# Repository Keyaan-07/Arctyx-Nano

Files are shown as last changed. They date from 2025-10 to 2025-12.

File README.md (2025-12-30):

# Arctyx Nano

Arctyx Nano is an FPGA development board carrying the ICE40UP5K FPGA from Lattice. It also carries RP2350A from Raspberry Pi.  

Check out the board on [KiCanvas](https://kicanvas.org/?github=https://github.com/Keyaan-07/Arctyx-Nano/tree/main/hardware_Arctyx-Nano)

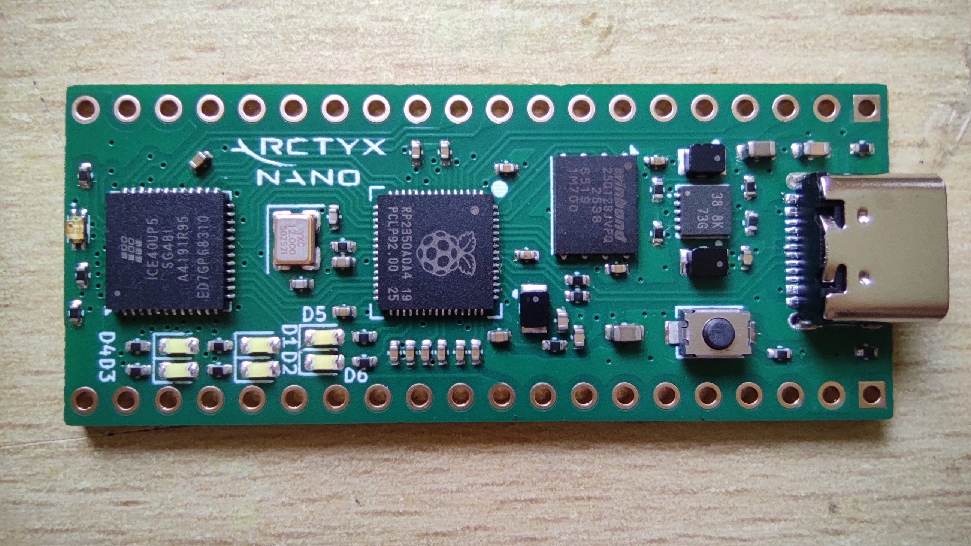
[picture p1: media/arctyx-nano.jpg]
assembled PCB

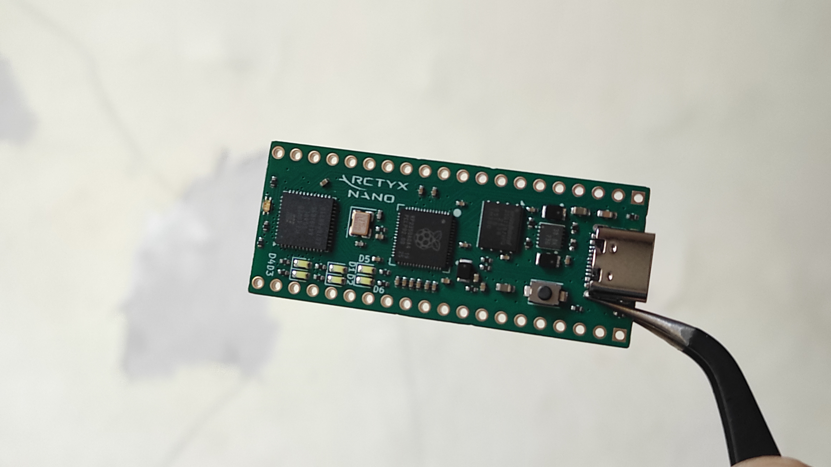
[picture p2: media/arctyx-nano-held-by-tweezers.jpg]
arctyx nano held by tweezers

  

## Features:
> Dual core ARM Cortex-M33 Processor (also everything else the RP2350 has)  
> 8 channel bus connecting the FPGA and the RP2350A  
> 128Mbit of Flash.  
> 6 General Purpose LEDs (4x for FPGA and 2x for RP2350A).  
> RGB LED connected to the FPGA.  
> Onboard Dual Stepdown Convertor.    
> USB Boot Button for RP2350A.  

## IO Pin mapping:

| Programmer Pin | Pin on FPGA | Pin on RP2350A |
| --- | --- | --- |
| CSn | IOB_35b_SPI_SS  | GPIO17 |
| MOSI | IOB_33b_SPI_SI  | GPIO19 |
| MISO | IOB_32a_SPI_SO  | GPIO20 |
| SCLK | IOB_34a_SPI_SCK | GPIO18 |

| Pin Label | Pin on FPGA | Pin label | Pin on FPGA |
| --- | --- | --- | --- |
| IO1 | IOT_41a | IO11 | IOB_4a |
| IO2 | IOT_42b | IO12 | IOB_6a |
| IO3 | IOT_43a | IO13 | IOB_9b |
| IO4 | IOT_44b | IO14 | IOB_9a |
| IO5 | IOT_46b | IO15 | IOB_13b |
| IO6 | IOT_48b | IO16 | IOB_16a |
| IO7 | IOT_45a | IO17 | IOB_18a |
| IO8 | IOT_50b | IO18 | IOB_20a |
| IO9 | IOT_51a | IO19 | IOB_22a |
| IO10 | IOT_49a | IO20 | IOB_24a |

| BUS Pin | Pin on FPGA | Pin on RP2350A |
| --- | --- | --- |
| BUS0 | IOT_38b | GPIO9 |
| BUS1 | IOT_39a | GPIO10 |
| BUS2 | IOT_36b | GPIO11 |
| BUS3 | IOT_37a | GPIO12 |
| BUS4 | IOB_23b | GPIO13 |
| BUS5 | IOB_25b_G3  | GPIO14 |
| BUS6 | IOB_29b | GPIO15 |
| BUS7 | IOB_31b | GPIO16 |

| LED | Pin On FPGA/MCU  |
| --- | ---  |
| D1  | IOB_0a |
| D2  | IOB_2a |
| D3  | IOB_5b |
| D4  | IOB_3b_G6 |
| D5  | GPIO21 |
| D6  | GPIO22 |
| RGB | RGB0, RGB1, RGB2 |

## BOM
| Item | Cost  | Note |
| --- | ----- | --- |
| PCB | 17.8  | 4-Layers |
| PCBA | 52.77 | Kinda Dense board  |
| Shipping charges  | 9.28  | |
| coupon Discount | \-9 | |
| Total | 70.85 | USD |

### PCB Components Breakdown
| Designator | Designation | Footprint | Quantity | Amount | JLCPCB Lib type | JLCPCB Part Number |
| --- | --- | --- | --- | --- | --- | --- |
| C1,C2 | 15p | 0402 | 4 | 0.004  | Basic | C1548 |
| C10,C11,C12,C13,C14,C15,C17,C18,C19,C21,C6,C7,C8,C9 | 100n | 0402 | 28 | 0.0336 | Basic | C1525 |
| C16,C23,C3,C4,C5 | 4.7u | 0402 | 10 | 0.049  | Basic | C23733 |
| C20,C22 | 22u | 0603 | 4 | 0.0348 | Basic | C59461 |
| C24 | 10u | 0603 | 2 | 0.0112 | Basic | C19702 |
| D1,D2,D3,D4,D5,D6 | LED | 0603 | 12 | 0.1224 | Extended | C2290 |
| L1,L2,L3 | AOTA-B201610S3R3-101-T | IND-SMD_L2.0-W1.6_AOTA-B201610S3R3-101-T | 6 | 1.0782 | Extended | C42411119 |
| R1,R2 | 5.1k | 0402 | 4 | 0.002  | Basic | C25905 |
| R3,R4 | 27 | 0402 | 20 | 0.012  | Extended | C138021 |
| R5,R7 | 1k | 0402 | 4 | 0.0024 | Basic | C11702 |
| R6 | 33 | 0402 | 2 | 0.0012 | Basic | C25105 |
| R10,R9 | 51k | 0402 | 4 | 0.0024 | Basic | C25794 |
| R11 | 100k | 0402 | 2 | 0.0012 | Basic | C25741 |
| R12 | 22k | 0402 | 2 | 0.0012 | Basic | C25768 |
| R13 | 120 | 0402 | 2 | 0.0012 | Basic | C25079 |
| R14,R15,R16,R17,R18,R19,R20,R21 | 100 | 0402 | 16 | 0.008  | Basic | C25076 |
| SW1 | SW_Push | SW-SMD_L3.9-W3.0-P4.45 | 2 | 0.0846 | Basic | C720477 |
| U1 | ICE40UP5K-SG48ITR | QFN-48-1EP_7x7mm_P0.5mm_EP5.6x5.6mm | 2 | 11.352 | Extended | C2678152 |
| U2 | RP2350A-QFN60 | RP2350A_QFN-60_EP_7.75x7.75_Pitch0.4mm | 2 | 3.195  | Extended | C42411118 |
| U3 | W25Q128JVP | WSON-8-1EP_6x5mm_P1.27mm_EP3.4x4.3mm | 2 | 2.472  | Extended | C2441427 |
| U4 | RT8075ZQW | WDFN-10_L3.0-W3.0-P0.50-BL-EP | 2 | 0.864  | Extended | C250416 |
| U5 | TJ-S1608SW6TDSLCCYRGB-A5 | LED-ARRAY-SMD_4P-L1.6-W0.8-BL-FD | 6 | 0.4314 | Extended | C5356078 |
| Y1 | Crystal_GND24 | Crystal_SMD_3225-4Pin_3.2x2.5mm | 2 | 0.1290  | Basic | C9002 |
| J1 | USB_C_Receptacle_USB2.0_16P | USB_C_Receptacle_XKB_U262-16XN-4BVC11 | 0 | 0 | Do Not Place | Do Not Place |

## License and Contribution

[MIT License](/LICENSE)

Open to contributions in both software and hardware!

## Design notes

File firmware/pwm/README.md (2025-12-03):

# PWM

This code makes all 3 RGB LEDs present on the Arctyx Nano have the fading effect. Here's a demo video:

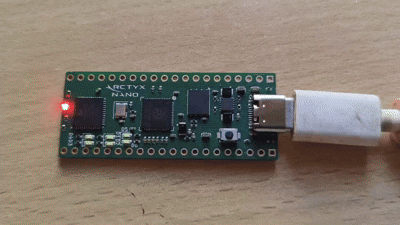
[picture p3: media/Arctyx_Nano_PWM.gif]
PWM Demo GIF


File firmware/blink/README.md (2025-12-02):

# Blink!

This code makes the RGB LEDs on the FPGA toggle. Here's a demo video:

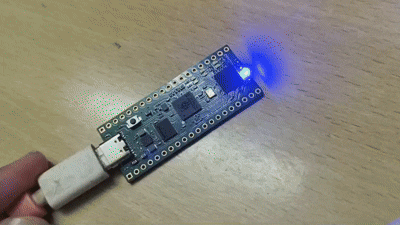
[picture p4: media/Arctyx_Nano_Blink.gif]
Arctyx Nano Blink


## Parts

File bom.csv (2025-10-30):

Item | Cost | Note
PCB | 17.8 | 4-Layers
PCBA | 52.77 | Kinda Dense board
Shipping from JLC | 9.28
coupon Discount | -9 | SMT monthly coupon
Total | 70.85 | USD

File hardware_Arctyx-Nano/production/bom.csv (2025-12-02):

Designator | Footprint | Quantity | Value | LCSC Part #
C1, C2 | 0402 | 2 | 15p
C10, C11, C12, C13, C14, C15, C17, C18, C19, C21, C6, C7, C8, C9 | 0402 | 14 | 100n
C16, C23, C3, C4, C5 | 0402 | 5 | 4.7u
C20, C22 | 0603 | 2 | 22u
C24 | 0603 | 1 | 10u
D1, D2, D3, D4, D5, D6 | 0603 | 6 | LED
J1 | USB_C_Receptacle_XKB_U262-16XN-4BVC11 | 1 | USB_C_Receptacle_USB2.0_16P
J2, J3 | PinHeader_1x20_P2.54mm_Vertical | 2 | Conn_01x20_Pin
L1, L2, L3 | IND-SMD_L2.0-W1.6_AOTA-B201610S3R3-101-T | 3 | AOTA-B201610S3R3-101-T | C42411119
R1, R2 | 0402 | 2 | 5.1k
R10, R9 | 0402 | 2 | 51k
R11 | 0402 | 1 | 22k
R12 | 0402 | 1 | 100k
R13 | 0402 | 1 | 120
R14, R15, R16, R17, R18, R19, R20, R21 | 0402 | 8 | 100
R3, R4 | 0402 | 2 | 27
R5, R7 | 0402 | 2 | 1k
R6 | 0402 | 1 | 33
SW1 | SW-SMD_L3.9-W3.0-P4.45 | 1 | SW_Push
TP1, TP2, TP3, TP4, TP5, TP6, TP7 | TestPoint_Pad_D1.0mm | 7 | TestPoint_Alt
U1 | QFN-48-1EP_7x7mm_P0.5mm_EP5.6x5.6mm | 1 | ICE40UP5K-SG48ITR
U2 | RP2350A_QFN-60_EP_7.75x7.75_Pitch0.4mm | 1 | RP2350A-QFN60
U3 | WSON-8-1EP_6x5mm_P1.27mm_EP3.4x4.3mm | 1 | W25Q128JVP
U4 | WDFN-10_L3.0-W3.0-P0.50-BL-EP | 1 | RT8075ZQW | C250416
U5 | LED-ARRAY-SMD_4P-L1.6-W0.8-BL-FD | 1 | TJ-S1608SW6TDSLCCYRGB-A5 | C5356078
Y1 | Crystal_SMD_3225-4Pin_3.2x2.5mm | 1 | Crystal_GND24

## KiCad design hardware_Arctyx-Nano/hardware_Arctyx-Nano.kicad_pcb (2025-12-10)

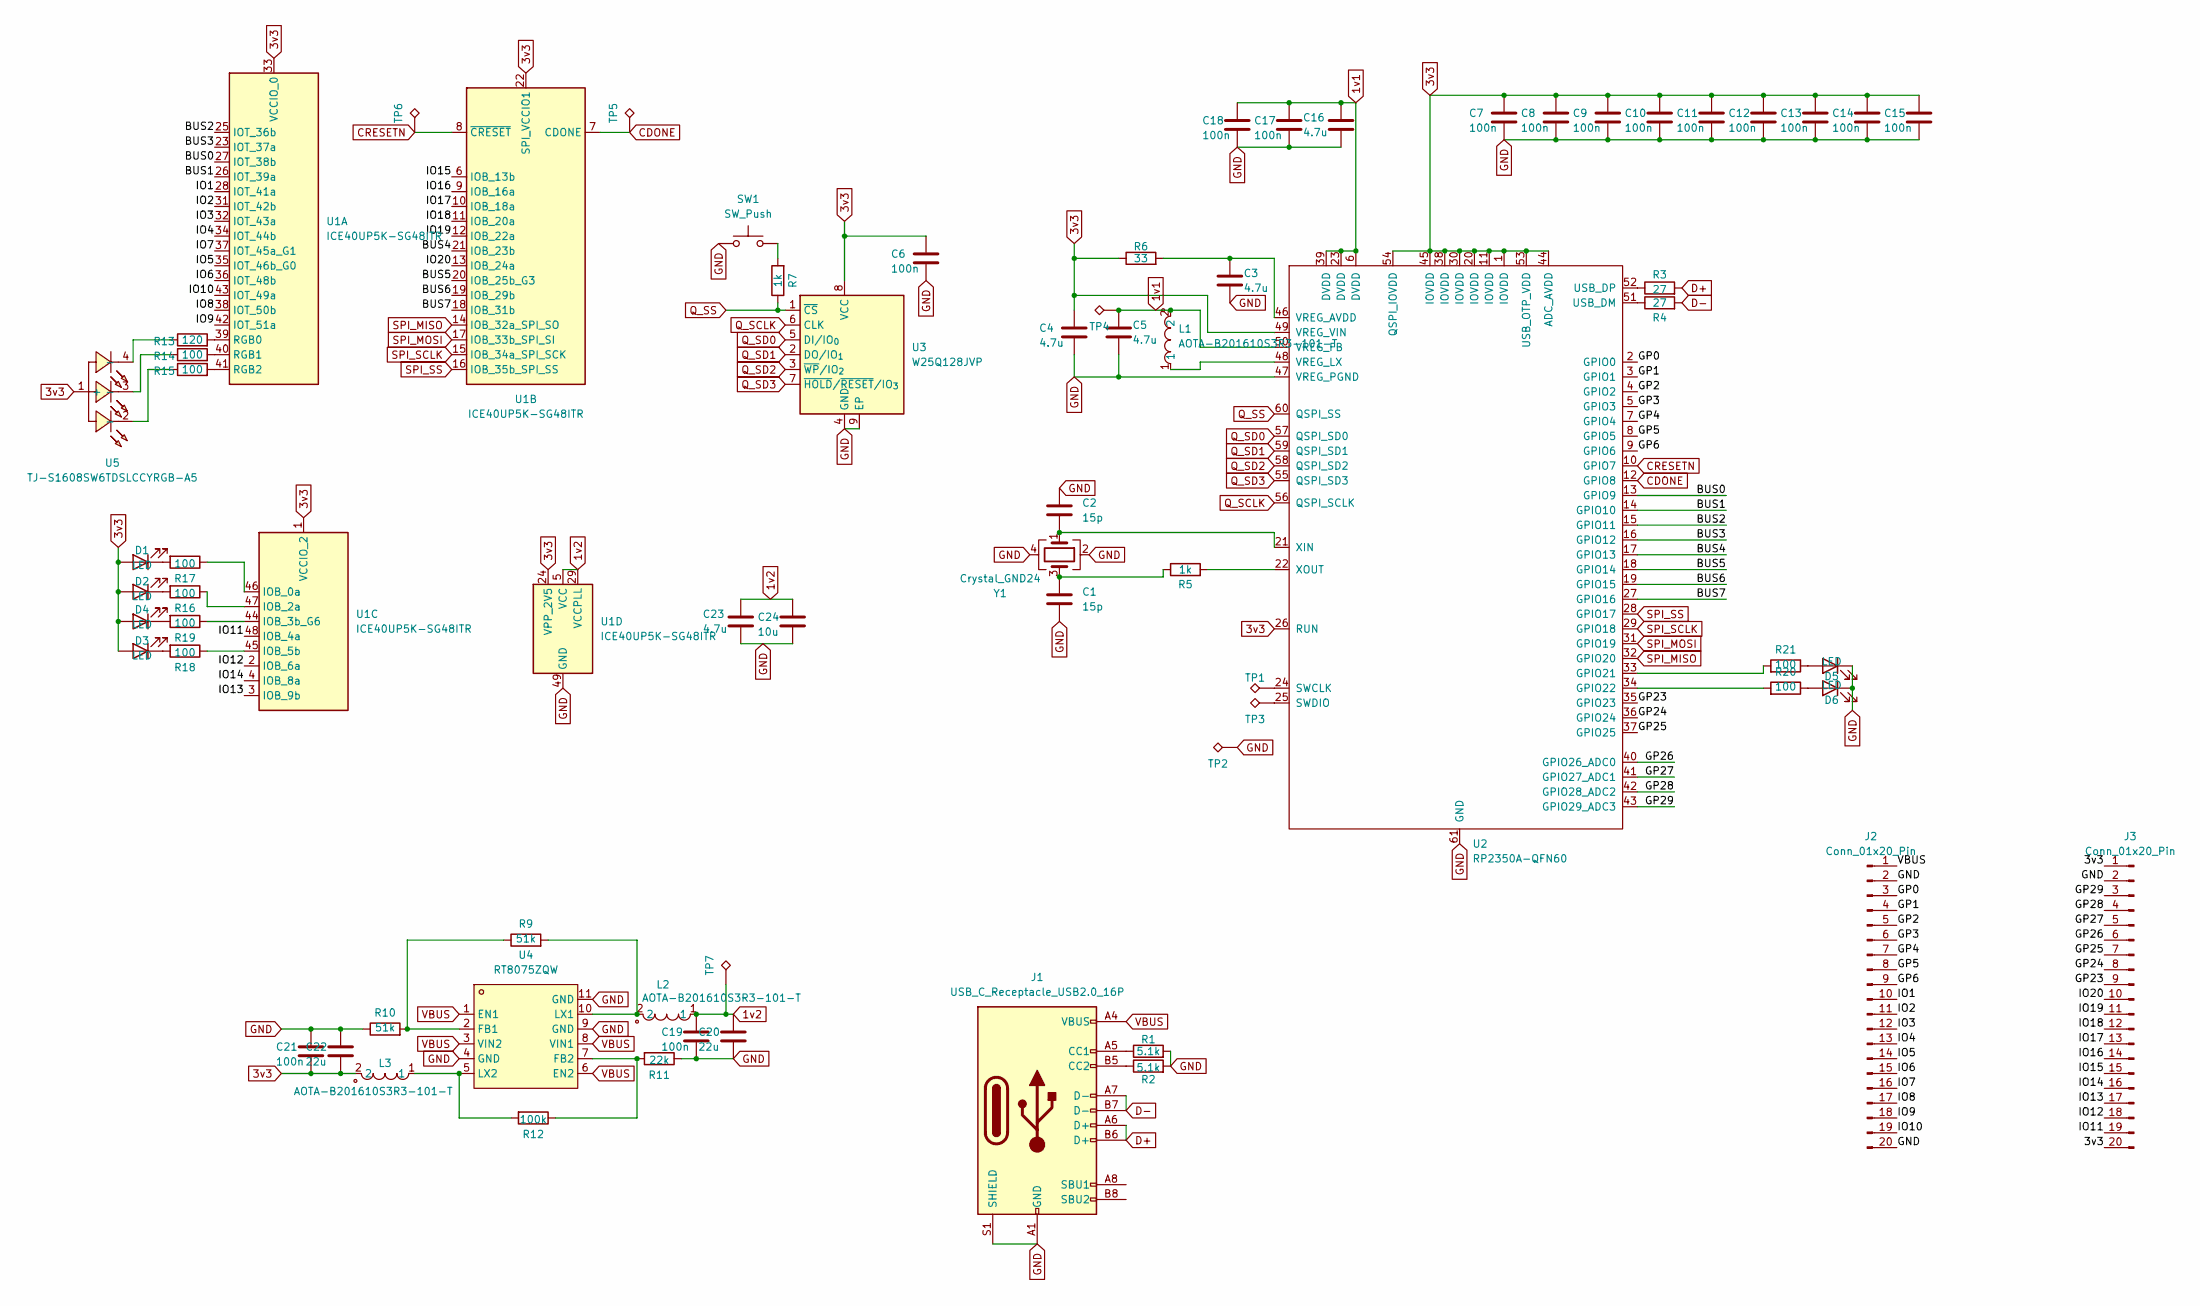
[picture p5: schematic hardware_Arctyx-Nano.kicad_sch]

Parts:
C1, C2: 15p; C_0402_1005Metric
C3, C4, C5, C16, C23: 4.7u; C_0402_1005Metric
C6, C7, C8, C9, C10, C11, C12, C13, C14, C15, C17, C18, C19, C21: 100n; C_0402_1005Metric
C20, C22: 22u; C_0603_1608Metric
C24: 10u; C_0603_1608Metric
D1, D2, D3, D4, D5, D6: LED; LED_0603_1608Metric
J1: USB_C_Receptacle_USB2.0_16P; USB_C_Receptacle_XKB_U262-16XN-4BVC11
J2, J3: Conn_01x20_Pin; PinHeader_1x20_P2.54mm_Vertical
L1, L2, L3: AOTA-B201610S3R3-101-T; IND-SMD_L2.0-W1.6_AOTA-B201610S3R3-101-T; LCSC Part C42411119
R1, R2: 5.1k; R_0402_1005Metric
R3, R4: 27; R_0402_1005Metric
R5, R7: 1k; R_0402_1005Metric
R6: 33; R_0402_1005Metric
R9, R10: 51k; R_0402_1005Metric
R11: 22k; R_0402_1005Metric
R12: 100k; R_0402_1005Metric
R13: 120; R_0402_1005Metric
R14, R15, R16, R17, R18, R19, R20, R21: 100; R_0402_1005Metric
SW1: SW_Push; SW-SMD_L3.9-W3.0-P4.45
TP1, TP2, TP3, TP4, TP5, TP6, TP7: TestPoint_Alt; TestPoint_Pad_D1.0mm
U1: ICE40UP5K-SG48ITR; QFN-48-1EP_7x7mm_P0.5mm_EP5.6x5.6mm
U2: RP2350A-QFN60; RP2350A_QFN-60_EP_7.75x7.75_Pitch0.4mm
U3: W25Q128JVP; WSON-8-1EP_6x5mm_P1.27mm_EP3.4x4.3mm
U4: RT8075ZQW; WDFN-10_L3.0-W3.0-P0.50-BL-EP; LCSC Part C250416
U5: TJ-S1608SW6TDSLCCYRGB-A5; LED-ARRAY-SMD_4P-L1.6-W0.8-BL-FD; LCSC Part C5356078
Y1: Crystal_GND24; Crystal_SMD_3225-4Pin_3.2x2.5mm

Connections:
1v1: C5.1, C16.1, C17.1, C18.1, L1.2, TP4.1, U2.6 (DVDD), U2.23 (DVDD), U2.39 (DVDD), U2.50 (VREG_FB)
1v2: C19.1, C20.1, C23.1, C24.1, L2.1, TP7.1, U1.5 (VCC), U1.29 (VCCPLL), U1.30 (VCC)
3v3: C4.1, C6.1, C7.1, C8.1, C9.1, C10.1, C11.1, C12.1, C13.1, C14.1, C15.1, C21.2, C22.2, D1.2 (A), D2.2 (A), D3.2 (A), D4.2 (A), J3.1, J3.20, L3.2, R6.1, U1.1 (VCCIO_2), U1.22 (SPI_VCCIO1), U1.24 (VPP_2V5), U1.33 (VCCIO_0), U2.1 (IOVDD), U2.11 (IOVDD), U2.20 (IOVDD), U2.26 (RUN), U2.30 (IOVDD), U2.38 (IOVDD), U2.44 (ADC_AVDD), U2.45 (IOVDD), U2.49 (VREG_VIN), U2.53 (USB_OTP_VDD), U2.54 (QSPI_IOVDD), U3.8 (VCC), U5.1 (+)
/BUS0: U1.27 (IOT_38b), U2.13 (GPIO9)
/BUS1: U1.26 (IOT_39a), U2.14 (GPIO10)
/BUS2: U1.25 (IOT_36b), U2.15 (GPIO11)
/BUS3: U1.23 (IOT_37a), U2.16 (GPIO12)
/BUS4: U1.21 (IOB_23b), U2.17 (GPIO13)
/BUS5: U1.20 (IOB_25b_G3), U2.18 (GPIO14)
/BUS6: U1.19 (IOB_29b), U2.19 (GPIO15)
/BUS7: U1.18 (IOB_31b), U2.27 (GPIO16)
/GP0: J2.3, U2.2 (GPIO0)
/GP1: J2.4, U2.3 (GPIO1)
/GP2: J2.5, U2.4 (GPIO2)
/GP3: J2.6, U2.5 (GPIO3)
/GP4: J2.7, U2.7 (GPIO4)
/GP5: J2.8, U2.8 (GPIO5)
/GP6: J2.9, U2.9 (GPIO6)
/GP23: J3.9, U2.35 (GPIO23)
/GP24: J3.8, U2.36 (GPIO24)
/GP25: J3.7, U2.37 (GPIO25)
/GP26: J3.6, U2.40 (GPIO26_ADC0)
/GP27: J3.5, U2.41 (GPIO27_ADC1)
/GP28: J3.4, U2.42 (GPIO28_ADC2)
/GP29: J3.3, U2.43 (GPIO29_ADC3)
/IO1: J2.10, U1.28 (IOT_41a)
/IO2: J2.11, U1.31 (IOT_42b)
/IO3: J2.12, U1.32 (IOT_43a)
/IO4: J2.13, U1.34 (IOT_44b)
/IO5: J2.14, U1.35 (IOT_46b_G0)
/IO6: J2.15, U1.36 (IOT_48b)
/IO7: J2.16, U1.37 (IOT_45a_G1)
/IO8: J2.17, U1.38 (IOT_50b)
/IO9: J2.18, U1.42 (IOT_51a)
/IO10: J2.19, U1.43 (IOT_49a)
/IO11: J3.19, U1.48 (IOB_4a)
/IO12: J3.18, U1.2 (IOB_6a)
/IO13: J3.17, U1.3 (IOB_9b)
/IO14: J3.16, U1.4 (IOB_8a)
/IO15: J3.15, U1.6 (IOB_13b)
/IO16: J3.14, U1.9 (IOB_16a)
/IO17: J3.13, U1.10 (IOB_18a)
/IO18: J3.12, U1.11 (IOB_20a)
/IO19: J3.11, U1.12 (IOB_22a)
/IO20: J3.10, U1.13 (IOB_24a)
CDONE: TP5.1, U1.7 (CDONE), U2.12 (GPIO8)
CRESETN: TP6.1, U1.8 (~CRESET), U2.10 (GPIO7)
D+: J1.A6 (D+), J1.B6 (D+), R3.2
D-: J1.A7 (D-), J1.B7 (D-), R4.2
GND: C1.2, C2.1, C3.2, C4.2, C5.2, C6.2, C7.2, C8.2, C9.2, C10.2, C11.2, C12.2, C13.2, C14.2, C15.2, C16.2, C17.2, C18.2, C19.2, C20.2, C21.1, C22.1, C23.2, C24.2, D5.1 (K), D6.1 (K), J1.A1 (GND), J1.A12 (GND), J1.B1 (GND), J1.B12 (GND), J1.S1 (SHIELD), J2.2, J2.20, J3.2, R1.2, R2.2, R10.1, R11.1, SW1.1, TP2.1, U1.49 (GND), U2.47 (VREG_PGND), U2.61 (GND), U3.4 (GND), U3.9 (EP), U4.4 (GND), U4.9 (GND), U4.11 (GND), Y1.2, Y1.4
unnamed: C1.1, R5.1, Y1.3
unnamed: D1.1 (K), R17.2
unnamed: D2.1 (K), R16.2
unnamed: D3.1 (K), R18.2
unnamed: D4.1 (K), R19.2
unnamed: D5.2 (A), R21.1
unnamed: D6.2 (A), R20.1
unnamed: J1.A5 (CC1), R1.1
unnamed: J1.B5 (CC2), R2.1
unnamed: R7.2, SW1.2
unnamed: R13.1, U5.4 (-)
unnamed: R14.1, U5.3 (-)
unnamed: R15.1, U5.2 (-)
unnamed: R13.2, U1.39 (RGB0)
unnamed: R14.2, U1.40 (RGB1)
unnamed: R15.2, U1.41 (RGB2)
unnamed: R17.1, U1.46 (IOB_0a)
unnamed: R16.1, U1.47 (IOB_2a)
unnamed: R19.1, U1.44 (IOB_3b_G6)
unnamed: R18.1, U1.45 (IOB_5b)
unnamed: R21.2, U2.33 (GPIO21)
unnamed: R20.2, U2.34 (GPIO22)
unnamed: TP1.1, U2.24 (SWCLK)
unnamed: TP3.1, U2.25 (SWDIO)
unnamed: R4.1, U2.51 (USB_DM)
unnamed: R3.1, U2.52 (USB_DP)
unnamed: C3.1, R6.2, U2.46 (VREG_AVDD)
unnamed: L1.1, U2.48 (VREG_LX)
unnamed: C2.2, U2.21 (XIN), Y1.1
unnamed: R5.2, U2.22 (XOUT)
unnamed: R9.1, R10.2, U4.2 (FB1)
unnamed: R11.2, R12.1, U4.7 (FB2)
unnamed: L2.2, R9.2, U4.10 (LX1)
unnamed: L3.1, R12.2, U4.5 (LX2)
Q_SCLK: U2.56 (QSPI_SCLK), U3.6 (CLK)
Q_SD0: U2.57 (QSPI_SD0), U3.5 (DI/IO_{0})
Q_SD1: U2.59 (QSPI_SD1), U3.2 (DO/IO_{1})
Q_SD2: U2.58 (QSPI_SD2), U3.3 (~WP/IO_{2})
Q_SD3: U2.55 (QSPI_SD3), U3.7 (~HOLD/~RESET/IO_{3})
Q_SS: R7.1, U2.60 (QSPI_SS), U3.1 (~CS)
SPI_MISO: U1.14 (IOB_32a_SPI_SO), U2.32 (GPIO20)
SPI_MOSI: U1.17 (IOB_33b_SPI_SI), U2.31 (GPIO19)
SPI_SCLK: U1.15 (IOB_34a_SPI_SCK), U2.29 (GPIO18)
SPI_SS: U1.16 (IOB_35b_SPI_SS), U2.28 (GPIO17)
VBUS: J1.A4 (VBUS), J1.A9 (VBUS), J1.B4 (VBUS), J1.B9 (VBUS), J2.1, U4.1 (EN1), U4.3 (VIN2), U4.6 (EN2), U4.8 (VIN1)

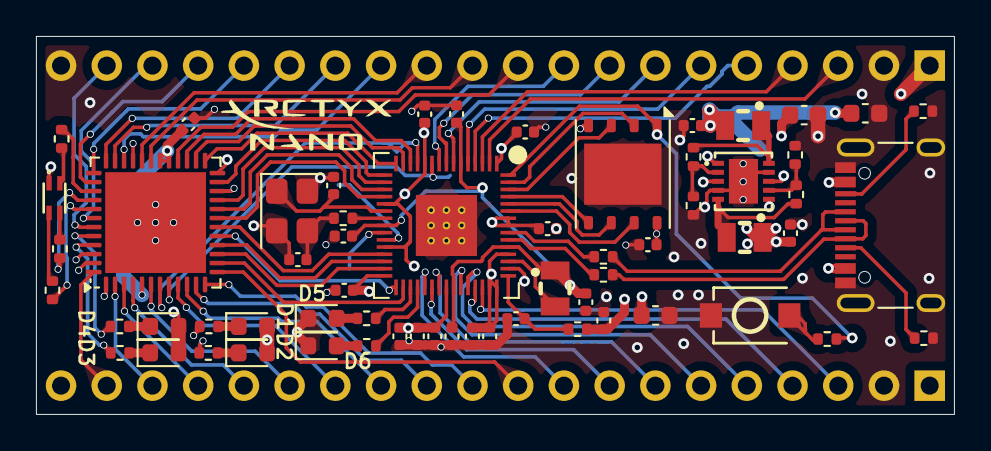
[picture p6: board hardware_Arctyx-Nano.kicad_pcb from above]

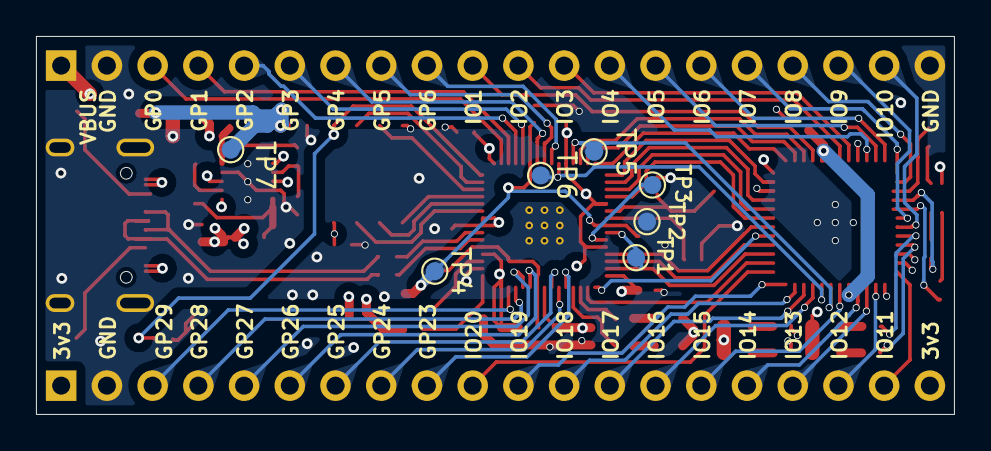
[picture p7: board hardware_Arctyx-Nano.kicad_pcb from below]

Board: 4 copper layers, 51.0 x 21.0 mm, 70 parts (9 on the bottom side), 95 nets.

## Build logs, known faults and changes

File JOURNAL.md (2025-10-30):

<!--
  ===================    !!READ THIS NOTICE!!   ====================
  DO NOT edit this file manually. Your changes WILL BE OVERWRITTEN!
  This journal is auto generated and updated by Hack Club Blueprint.
  To edit this file, please edit your journal entries on Blueprint.
  ==================================================================
-->

## 10/4/2025 - deciding stuff  

so, i have decided that i will be making an FPGA dev board in a raspi pico form factor, which will have the ice40up5k FPGA with 5280 LUTs. Here are some other things that i will need:

- A programming interface
- a flash storage
- cramming everything in rpi pico form factor
- USB-C
- required voltage regulators(3.3v and 1.2v prolly)
- too many LEDs(with suitable resistors)
Yeah that's all ig
and yes no castellations because they are expensive, and i'll solder the board myself at home yay  
idea

## 10/6/2025 - Idea Changed  

There are some things i want to change, first of all, i cannot figure out how to program the FPGA, as there are two ways, first you use a flash configured where the FPGA is the SPI master and the second is programming from an external MCU, where the FPGA acts as a slave. So i have an idea, I WILL USE THE RP2350 along with the FPGA. So yes, the board cost will be upped a little bit ig. i will still try to maintain the rpi pico form factor and use all the GPIOs, but if it is not possible then also it is fine as i will have many many GPIOs.

here are other things that i have decided to put:
1x RGB LED.
4x normal LEDs
2x power LEDs(3.3v and 1.2v both)
a buck convertor with 2 channels (most probably [RT8075ZQW](https://www.lcsc.com/product-detail/C250416.html))

it would look something like this:
2nd idea.png

## 10/13/2025 - Started with the schematic + minor placement  

umm yeah, i started with the schematic for the devboard, it went well.  

first i couldn't figure out some things like different voltages and i was concerced if i would need 2.5 volts too. but some wise people on the internet told that i can tie the VPP_2V5 pin to 3.3v directly. so yeah here it is.  

  

and i think i will have to share a lot of GPIO to output to the headers. the space is very very small.  

here's how the power part(dual buck converter) looks like:  
  

I basically wired the basics of FPGA and the rp2350a. now in the next sesh i will connect both the chips and add headers and hopefully i will be done with the schematic.  



## 10/20/2025 10 AM - Schematic Done!  

Yes, i finished the schematic, and i changed my flash to W25q128JVP instead of W25q128JVS because the JVS was too big for the board and JVP is significantly smaller and thus helps with space. i have realised that the board will be very tightly made and i will have to choose assembly as the items are placed very very closely. i have added a lot of LEDs too to not not use any GPIO pin. as well as i have 8 wires connecting the two semiconductors together. i still have to search for suitable LEDs and then assign resistor values.


## 10/20/2025 5 PM - Started with the PCB routing  

I started with the PCB routing, and i am aiming for a 2 layer PCB because idk. But like i am facing a lot of issues with routing, it is real hard to route. The two ICs make it a lot lot harder to route. i have yet not placed and routed with the power part of the board because that is a pain and the bottom part of the PCB looks beautiful but a lot of routing is left there too. will prolly do it later.  

  

## 10/21/2025 - Finished PCB routing  

okay, I finally completed the PCB.. I can ship it just now after making the BOM and beautifying the repo but no, i choose to make the dev board better, fix a lot of mistakes prolly and add all the 3d models. i want this project to be as polished as possible from my side. I still have to assign values to a resistor or two and i'll do that later too. Here's some images:




## 10/25/2025 1 PM - Removed silkscreen references + removed excess routes  

removed extra traces like random traces connecting 3v3 because i switched to 4 layers(made the routing so much easier as there were a few nets that were impossible to route). i made the PCB better overall. GPIO headers are yet to be added and i will add them later today. i also have to find a suitable resistor and add it's value. and yeah i have to add 3d models too along with branding and naming.  



## 10/25/2025 6 PM - PCB Complete!  

I completed the PCB. Changed a few nets, added a 10uF cap for the 1.2v rail. added all the different 3d models, and idk why but it was a pain to find the RP2350A 3d model. About everything is complete, will finish beautifying the repo and make the BOM and senD it! Check out the Images:  
  
  
  

## 10/26/2025 - Branding+BOM  

Okay, i did the branding for the board, it looks really cool!  
I mainly added resistor values as well as branding. the font i used is just a spacex clone because it looks really cool. uhh yea i am gonna make BOM next and i hope it works!
I reoriented the PCB to so it looks better in the PCB editor.






## 10/30/2025 - BOM optiimisation!  

I uhh changed the LEDs from 0402 Extended to 0603 basic and uhm i changed how they were placed on the board and i will now be using the C9002 crystal, thanks Kai! Will update the BOM and the costs. Here are the new images:





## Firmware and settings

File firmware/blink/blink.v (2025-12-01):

module rgb_test (output reg led_red,
           output reg led_green,
           output reg led_blue
);

wire clk;


SB_HFOSC #(
    .CLKHF_DIV("0b10") // 00=48MHz, 01=24MHz, 10=12MHz, 11=6MHz
) u_hfosc (
    .CLKHFEN(1'b1),    
    .CLKHFPU(1'b1),    
    .CLKHF(clk)
);


localparam N = 22;  //-- N<=21 Fast, N>=23 Slow

reg [N:0] counter;
reg [1:0] led_state;

always @(posedge clk) begin
  counter <= counter + 1;
  if (counter == 0) begin
    if (led_state == 2) begin
        led_state <= 0;
    end else begin
        led_state <= led_state + 1;
    end
  end
end

always @(*) begin
    
    led_red   = 1;
    led_green = 1;
    led_blue  = 1;


    case (led_state)
        2'd0: led_red   = 0;
        2'd1: led_green = 0;
        2'd2: led_blue  = 0;
        default: ;
    endcase
end

endmodule

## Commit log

2025-10-20 Routing the PCB
    [hardware_Arctyx-Nano.kicad_pcb, hardware_Arctyx-Nano.kicad_sch]
2025-10-21 PCB Routing
    [hardware_Arctyx-Nano.kicad_pcb, hardware_Arctyx-Nano.kicad_sch]
2025-10-22 Fixing Silkscreen
    [hardware_Arctyx-Nano.kicad_pcb]
2025-10-25 removed reference labels
    [hardware_Arctyx-Nano.kicad_pcb]
2025-10-25 removed reference labels in PCB
2025-10-25 PCB fixing errors
    [hardware_Arctyx-Nano.kicad_pcb, hardware_Arctyx-Nano.kicad_sch]
2025-10-26 production files generation and branding
    [bom.csv, designators.csv, hardware_Arctyx-Nano.kicad_pcb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]
2025-10-26 fixing rp2350 footprint
    [bom.csv, designators.csv, hardware_Arctyx-Nano.kicad_pcb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]
2025-10-26 gerber generated
2025-10-29 Added BOM
2025-10-29 BOM.csv added
    [bom.csv]
2025-10-30 BOM Optimisation
    [bom.csv, hardware_Arctyx-Nano.kicad_pcb, hardware_Arctyx-Nano.kicad_sch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]
2025-10-30 Fix LED reference
    [hardware_Arctyx-Nano.kicad_pcb, hardware_Arctyx-Nano.kicad_sch]
2025-12-01 images of assembled PCB added!
2025-12-02 update load capacitor values
    [bom.csv, hardware_Arctyx-Nano.kicad_pcb, hardware_Arctyx-Nano.kicad_sch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]
2025-12-03 added PWM example
2025-12-03 PWM gif
2025-12-10 Removed via-in-pad
    [hardware_Arctyx-Nano.kicad_pcb]
